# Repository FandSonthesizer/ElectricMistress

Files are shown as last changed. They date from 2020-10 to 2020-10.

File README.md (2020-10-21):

# ElectricMistress
This is the F&S version of this classic flanger effect. We based our PCB on the schematics from Thomeeque's EM3207.
Sounds really nice and is reasonable easy to build, check out our demo on youtube https://www.youtube.com/watch?v=bW4K1UdQq3Q

How does it work?
The mn3207 does contain a memory of 1024 steps, the 'bucket brigade'. The analog signal goes in, moves through the 'brigade' and goes to the output stage.
The faster the chip is clocked, the shorter the delay time is and vice versa. 
The clock is generated by a VCO around the LM311, then it is converted to the bi-phase clock signal the BBD chip needs. The VCO itself is modulated by the LFO consisting of U3 a,b,c. The clock rate varies from around 100kHz to a couple of hundred kHz. U1a boosts the input signal and U1b takes care of the feedback mix. Q1 is the output driver.

Fun fact: the clock driver cd4049 can be substituted by a cd4050 chip.

We have included a tiff file that you can print, cut out and fold around a 1590bb enclosure to let you know where to drill the holes.

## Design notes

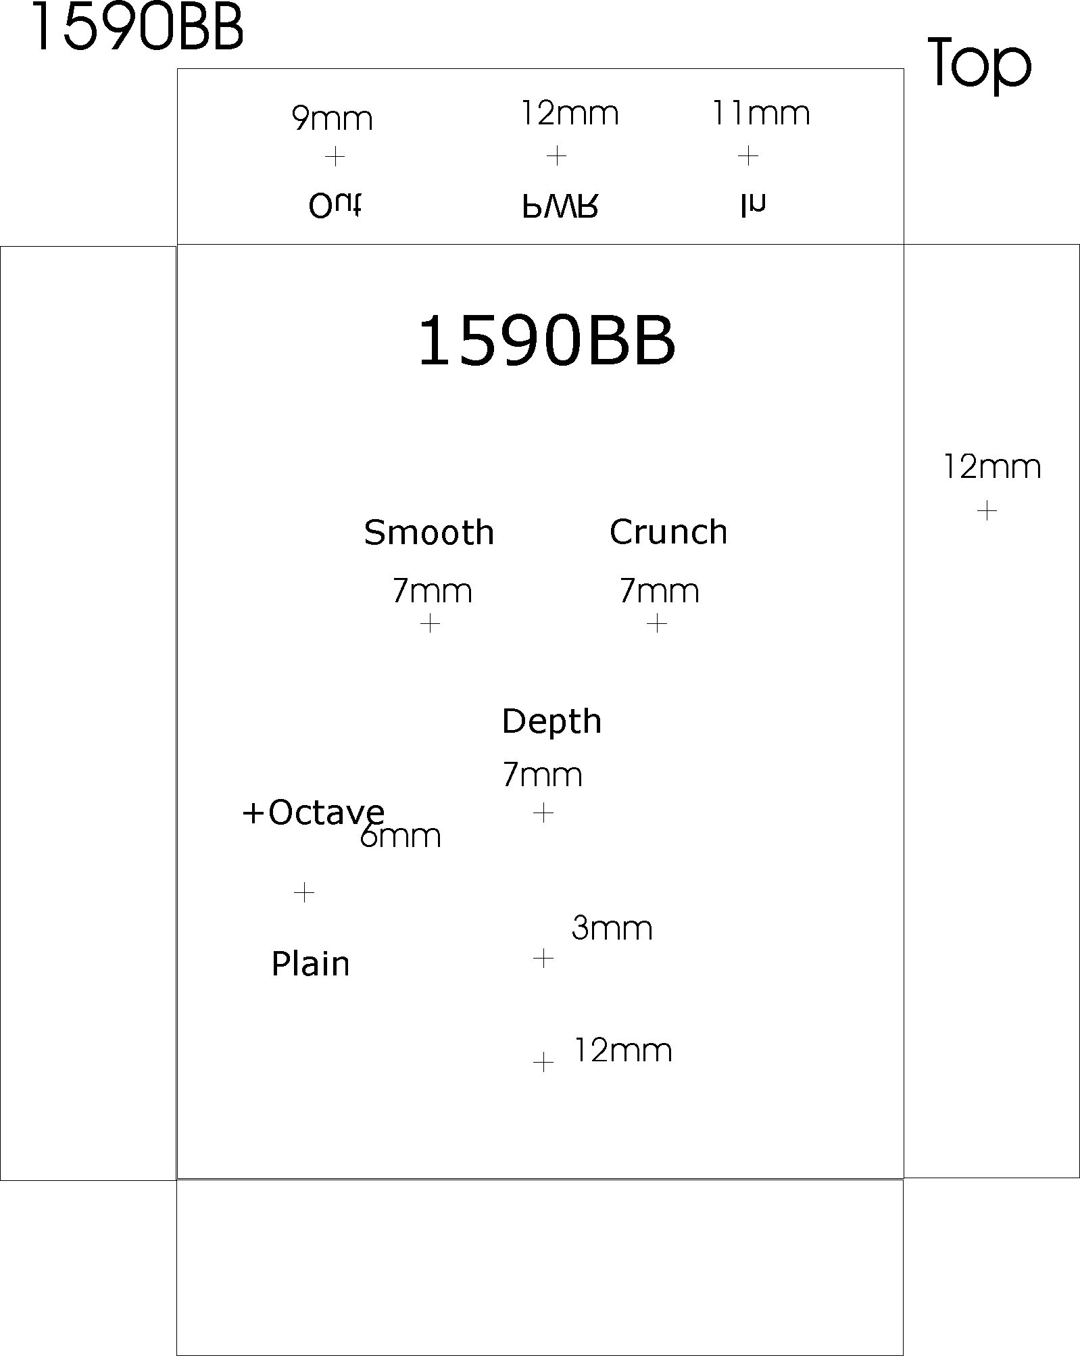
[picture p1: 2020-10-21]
Mistress/MistressFront.TIF

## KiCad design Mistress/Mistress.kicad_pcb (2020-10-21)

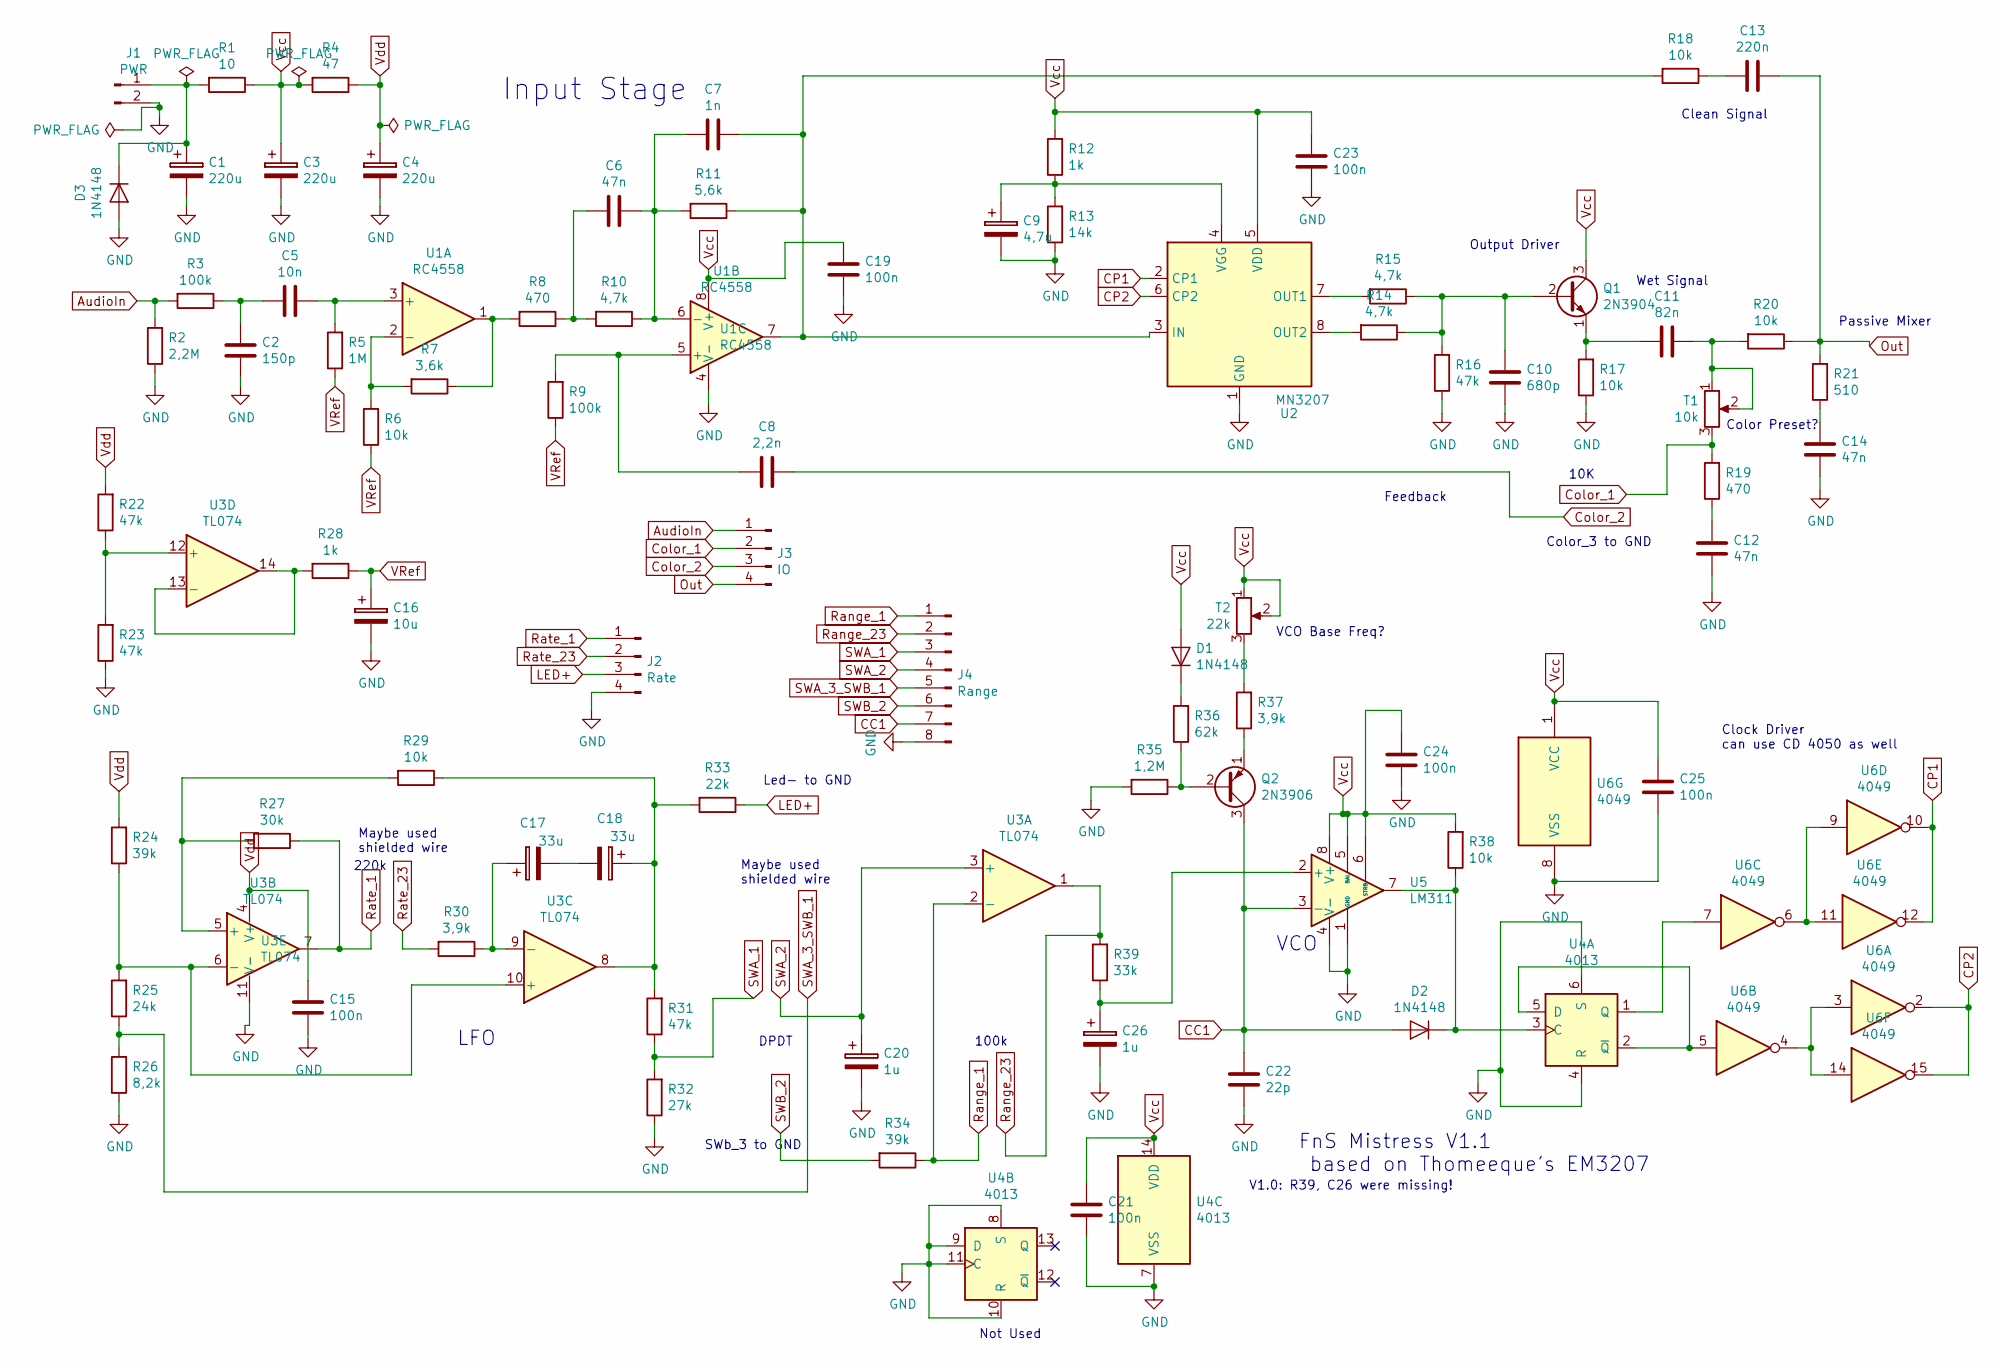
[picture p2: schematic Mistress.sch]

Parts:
C1, C3, C4: 220u; Elko_D6.3mm_P2.50mm
C2: 150p; Kondensator_Keramik
C5: 10n; Kondensator_Keramik
C6, C12, C14: 47n; Kondensator_Keramik
C7: 1n; Kondensator_Keramik
C8: 2,2n; Kondensator_Keramik
C9: 4,7u; Elko_D6.3mm_P2.50mm
C10: 680p; Kondensator_Keramik
C11: 82n; Kondensator_Keramik
C13: 220n; Kondensator_Keramik
C15, C19, C21, C23, C24, C25: 100n; Kondensator_Keramik
C16: 10u; Elko_D6.3mm_P2.50mm
C17, C18: 33u; Elko_D6.3mm_P2.50mm
C20, C26: 1u; Elko_D6.3mm_P2.50mm
C22: 22p; Kondensator_Keramik
D1, D2, D3: 1N4148; Diode_Horizontal
J1: PWR; Stift_x02
J2: Rate; PinHeader_1x04_P2.54mm_Vertical_NIK
J3: IO; PinHeader_1x04_P2.54mm_Vertical_NIK
J4: Range; PinHeader_1x08_P2.54mm_Vertical_Nik
Q1: 2N3904; TO-92_Wide_NIK
Q2: 2N3906; TO-92_Wide_NIK
R1: 10; Widerstand_liegend
R2: 2,2M; Widerstand_liegend
R3, R9: 100k; Widerstand_liegend
R4: 47; Widerstand_liegend
R5: 1M; Widerstand_liegend
R6, R17, R18, R20, R29, R38: 10k; Widerstand_liegend
R7: 3,6k; Widerstand_liegend
R8, R19: 470; Widerstand_liegend
R10, R14, R15: 4,7k; Widerstand_liegend
R11: 5,6k; Widerstand_liegend
R12, R28: 1k; Widerstand_liegend
R13: 14k; Widerstand_liegend
R16, R22, R23, R31: 47k; Widerstand_liegend
R21: 510; Widerstand_liegend
R24, R34: 39k; Widerstand_liegend
R25: 24k; Widerstand_liegend
R26: 8,2k; Widerstand_liegend
R27: 30k; Widerstand_liegend
R30, R37: 3,9k; Widerstand_liegend
R32: 27k; Widerstand_liegend
R33: 22k; Widerstand_liegend
R35: 1,2M; Widerstand_liegend
R36: 62k; Widerstand_liegend
R39: 33k; Widerstand_liegend
T1: 10k; Trimmer_Vertical
T2: 22k; Trimmer_Vertical
U1: RC4558; DIP-8_W7.62mm_Socket_LongPads
U2: MN3207; DIP-8_W7.62mm_Socket_LongPads
U3: TL074; DIP-14_W7.62mm_Socket_LongPads
U4: 4013; DIP-14_W7.62mm_Socket_LongPads
U5: LM311; DIP-8_W7.62mm_Socket_LongPads
U6: 4049; DIP-16_W7.62mm_Socket_LongPads

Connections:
AudioIn: J3.1, R2.2, R3.2
CC1: C22.1, D2.2 (A), J4.7, Q2.3 (C), U5.3 (-)
CP1: U2.2 (CP1), U6.10, U6.12
CP2: U2.6 (CP2), U6.2, U6.15
Color_1: J3.2, R19.2, T1.3
Color_2: C8.1, J3.3
GND: C1.2, C2.2, C3.2, C4.2, C9.2, C10.2, C12.1, C14.1, C15.2, C16.2, C19.2, C20.2, C21.2, C22.2, C23.2, C24.2, C25.2, C26.2, D3.2 (A), J1.2, J2.4, J4.8, R2.1, R13.1, R16.1, R17.1, R23.1, R26.1, R32.1, R35.2, U1.4 (V-), U2.1 (GND), U3.11 (V-), U4.4 (R), U4.6 (S), U4.7 (VSS), U4.8 (S), U4.9 (D), U4.10 (R), U4.11 (C), U5.1 (GND), U5.4 (V-), U6.8 (VSS)
LED+: J2.3, R33.1
unnamed: C1.1, D3.1 (K), J1.1, R1.2
unnamed: C2.1, C5.2, R3.1
unnamed: C5.1, R5.2, U1.3 (+)
unnamed: C6.1, C7.2, R10.1, R11.2, U1.6 (-)
unnamed: C6.2, R8.1, R10.2
unnamed: C7.1, R11.1, R18.2, U1.7, U2.3 (IN)
unnamed: C8.2, R9.2, U1.5 (+)
unnamed: C9.1, R12.1, R13.2, U2.4 (VGG)
unnamed: C10.1, Q1.2 (B), R14.1, R15.1, R16.2
unnamed: C11.1, R20.2, T1.1, T1.2
unnamed: C11.2, Q1.1 (E), R17.2
unnamed: C12.2, R19.1
unnamed: C13.2, R18.1
unnamed: C14.2, R21.1
unnamed: C17.1, R30.1, U3.9 (-)
unnamed: C17.2, C18.2
unnamed: C18.1, R29.1, R31.2, R33.2, U3.8
unnamed: C26.1, R39.1, U5.2 (+)
unnamed: D1.1 (K), R36.2
unnamed: D2.1 (K), R38.1, U4.3 (C), U5.7
unnamed: Q2.1 (E), R37.1
unnamed: Q2.2 (B), R35.1, R36.1
unnamed: R6.2, R7.2, U1.2 (-)
unnamed: R7.1, R8.2, U1.1
unnamed: R14.2, U2.8 (OUT2)
unnamed: R15.2, U2.7 (OUT1)
unnamed: R22.1, R23.2, U3.12 (+)
unnamed: R24.1, R25.2, U3.6 (-), U3.10 (+)
unnamed: R27.2, R29.2, U3.5 (+)
unnamed: R28.2, U3.13 (-), U3.14
unnamed: R37.2, T2.3
unnamed: U4.1 (Q), U6.7
unnamed: U4.2 (~Q), U4.5 (D), U6.5
unnamed: U6.6, U6.9, U6.11
unnamed: U6.3, U6.4, U6.14
Out: C13.1, J3.4, R20.1, R21.2
Range_1: J4.1, R34.1, U3.2 (-)
Range_23: J4.2, R39.2, U3.1
Rate_1: J2.1, R27.1, U3.7
Rate_23: J2.2, R30.2
SWA_1: J4.3, R31.1, R32.2
SWA_2: C20.1, J4.4, U3.3 (+)
SWA_3_SWB_1: J4.5, R25.1, R26.2
SWB_2: J4.6, R34.2
VRef: C16.1, R5.1, R6.1, R9.1, R28.1
Vcc: C3.1, C19.1, C21.1, C23.1, C24.1, C25.1, D1.2 (A), Q1.3 (C), R1.1, R4.2, R12.2, R38.2, T2.1, T2.2, U1.8 (V+), U2.5 (VDD), U4.14 (VDD), U5.5 (BAL), U5.6 (STRB), U5.8 (V+), U6.1 (VCC)
Vdd: C4.1, C15.1, R4.1, R22.2, R24.2, U3.4 (V+)

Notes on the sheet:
220k
DPDT
100k
Color_3 to GND
10K
SWb_3 to GND
VCO Base Freq?
Color Preset?
FnS Mistress V1.1 based on Thomeeque's EM3207
Clock Driver can use CD 4050 as well
Not Used
VCO
LFO
Input Stage
Output Driver
Clean Signal
Wet Signal
Passive Mixer
Feedback
Maybe used shielded wire
Led- to GND
V1.0: R39, C26 were missing!

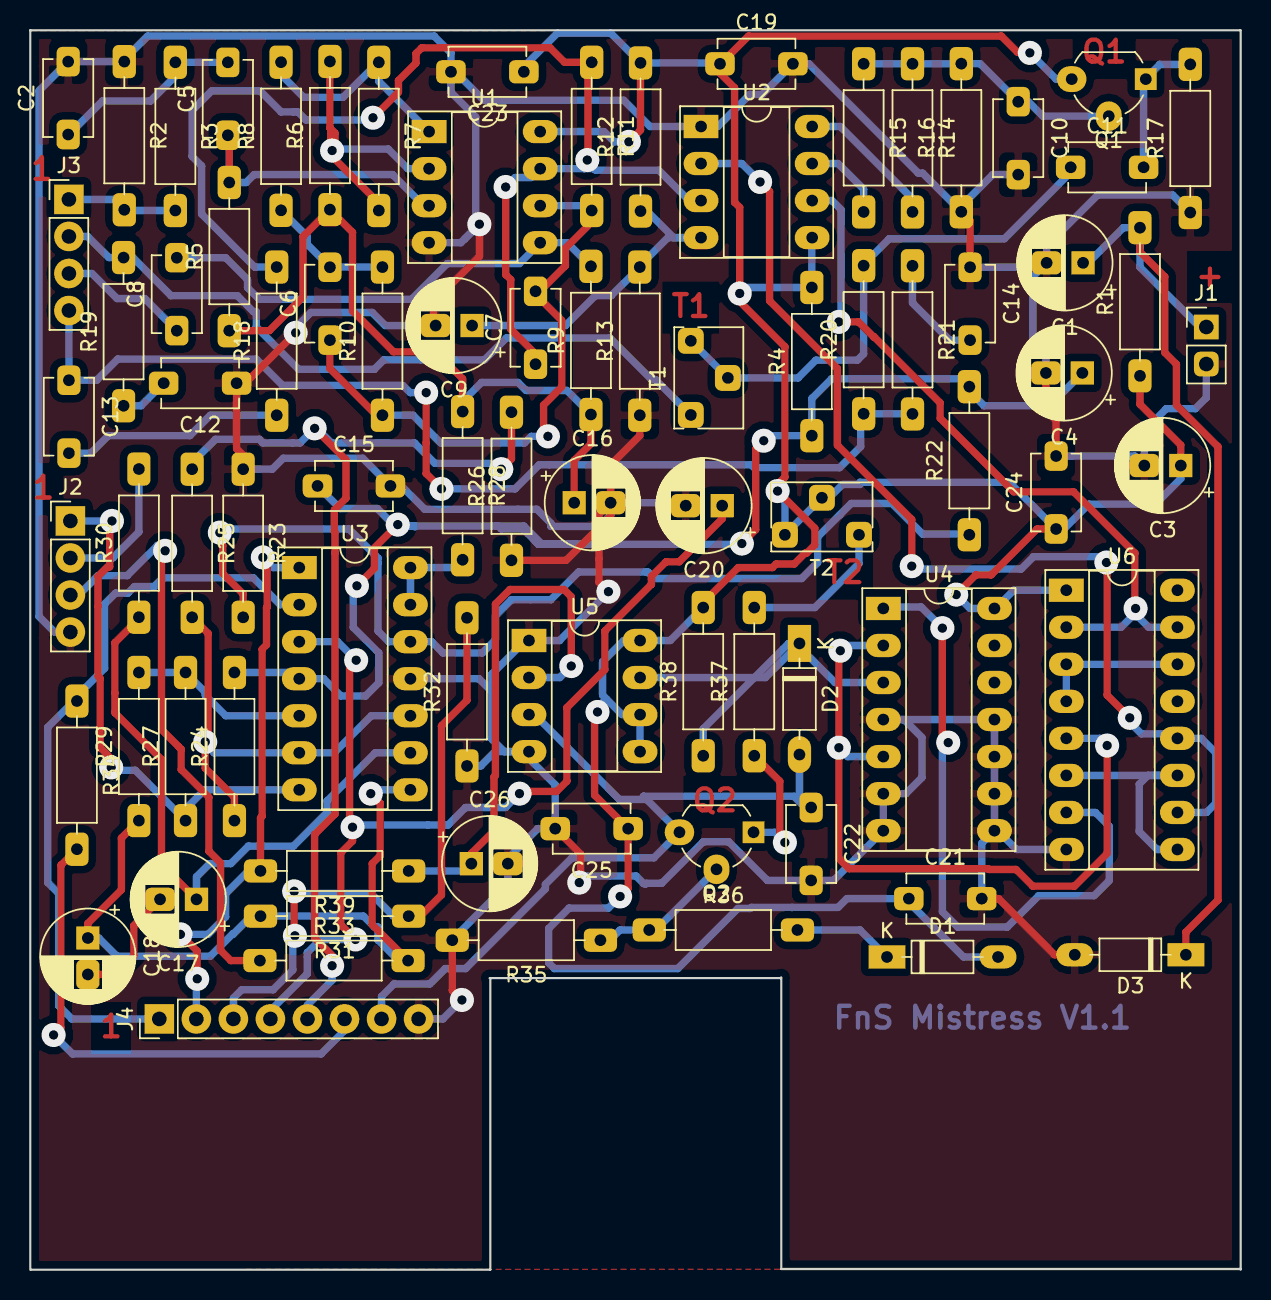
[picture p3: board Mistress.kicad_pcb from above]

Board: 2 copper layers, 83.0 x 85.0 mm, 82 parts (0 on the bottom side), 55 nets.
